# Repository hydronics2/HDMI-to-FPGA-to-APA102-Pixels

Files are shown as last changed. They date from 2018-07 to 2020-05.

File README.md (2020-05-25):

# Oregon Museum of Science & Industry (OMSI) - giant LED wall

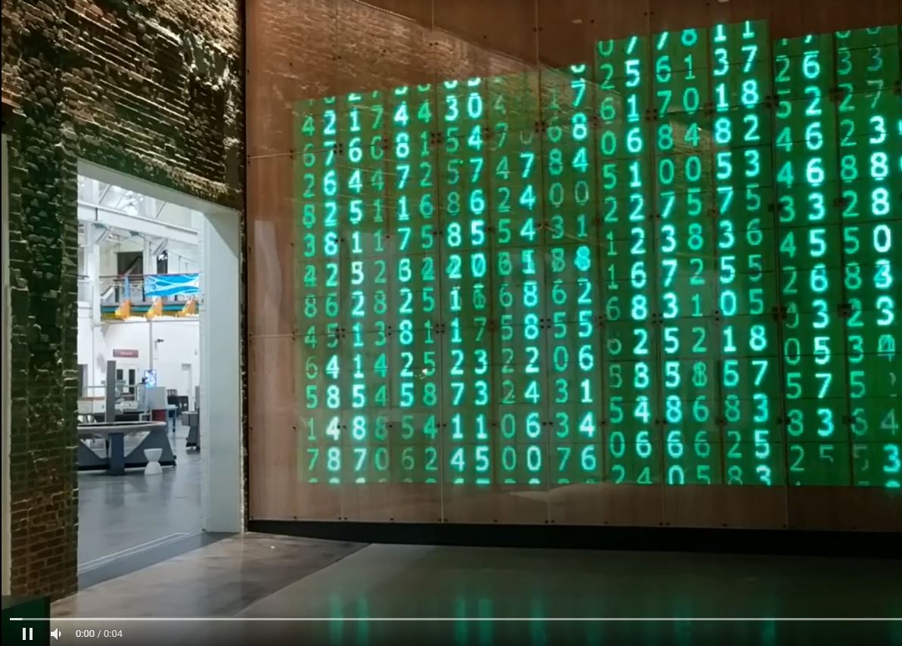
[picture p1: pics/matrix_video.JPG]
Foo (https://photos.app.goo.gl/FNSjgucNsmASgbaz8)

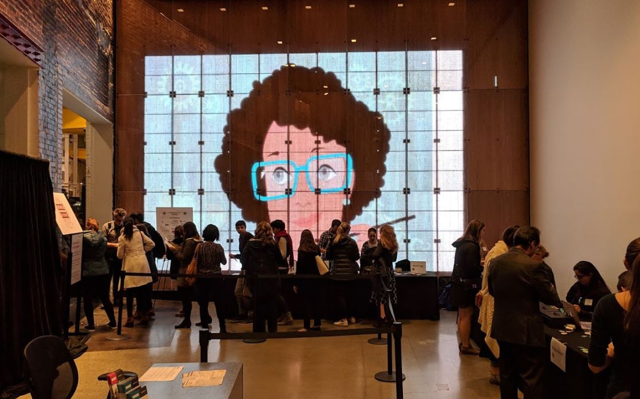
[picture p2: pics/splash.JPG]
splash

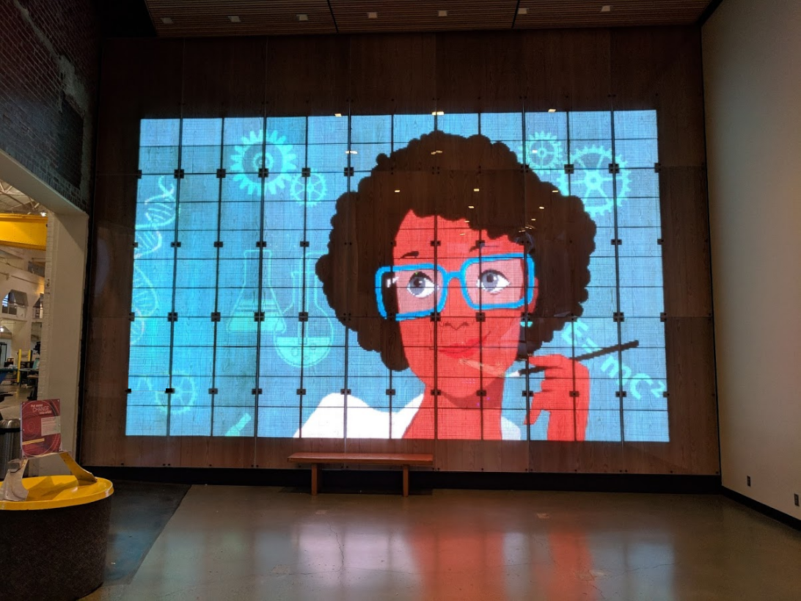
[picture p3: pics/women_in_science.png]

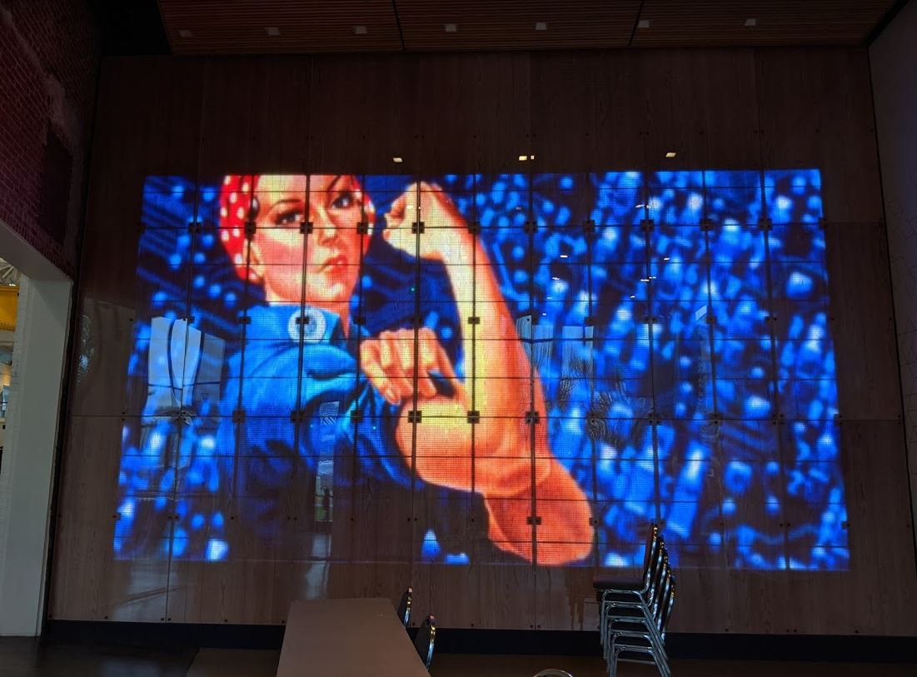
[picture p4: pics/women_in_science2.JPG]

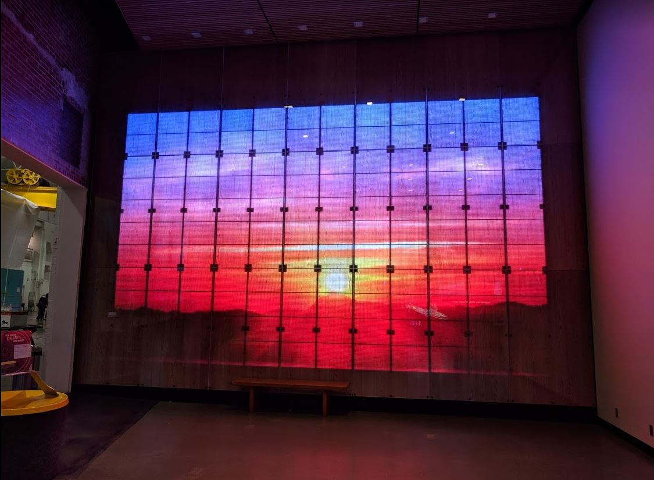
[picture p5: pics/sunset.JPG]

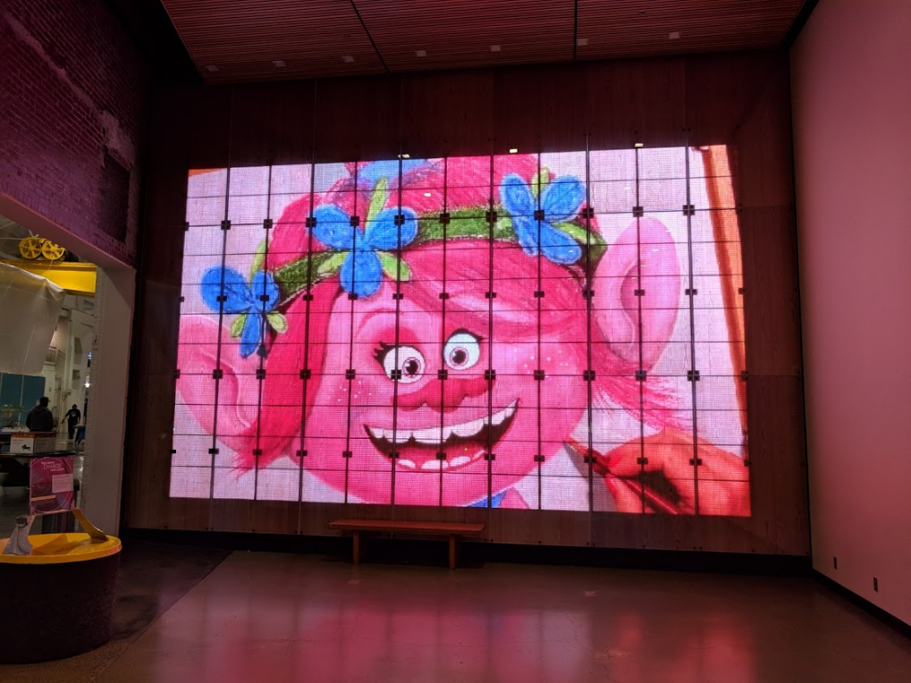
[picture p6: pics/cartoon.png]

132 APA102 LED panels, 680 pixels per panel, 90,000 pixels, 300sqft, 4 Spartan 6 Mojo FPGAs
[hackaday.io](https://hackaday.io/project/163657-hdmi-to-fpga-to-apa102)

LED Wall at Oregon Museum of Science & Industry(OMSI): https://photos.app.goo.gl/8hZoa7y9F9Lsg7Md9 (animation credit to [yassi @ openprocessing.org](https://www.openprocessing.org/user/65007))

The creative director wanted to put the LED display behind a wood grain pattern similar to the wall at Microsoft HQ. When the LEDs are off the visitor sees a seemless, unobtrusive wall. To make the LEDs pop behind the wood grain graphic we used a very brigtht APA102.

The resolution is about 24' wide by 14' high. That's 408 pixels wide 220 pixels tall. Not quite VGA.

The FPGA's boards are Spartan 6 on a Mojo development platform: https://alchitry.com/ The wall is broken down into 4 sections for 4 Mojo's and each Mojo receives the same HDMI signal but only grabs pixels for the section of LEDs it controls.

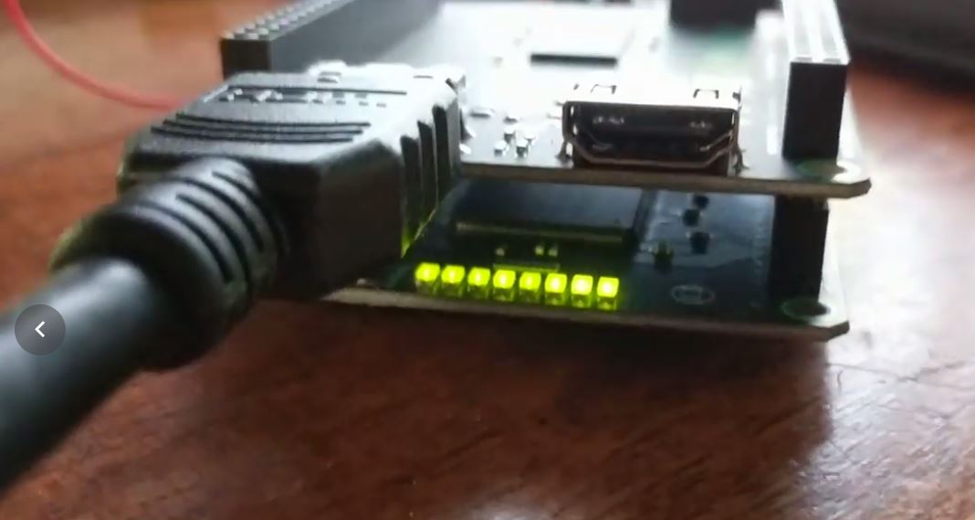
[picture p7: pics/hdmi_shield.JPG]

Alchitry has an HDMI shield for the Mojo and the FPGA code is written in their programming environment in Lucid a form of Verilog. It's great for beginners. This was my first FPGA project.

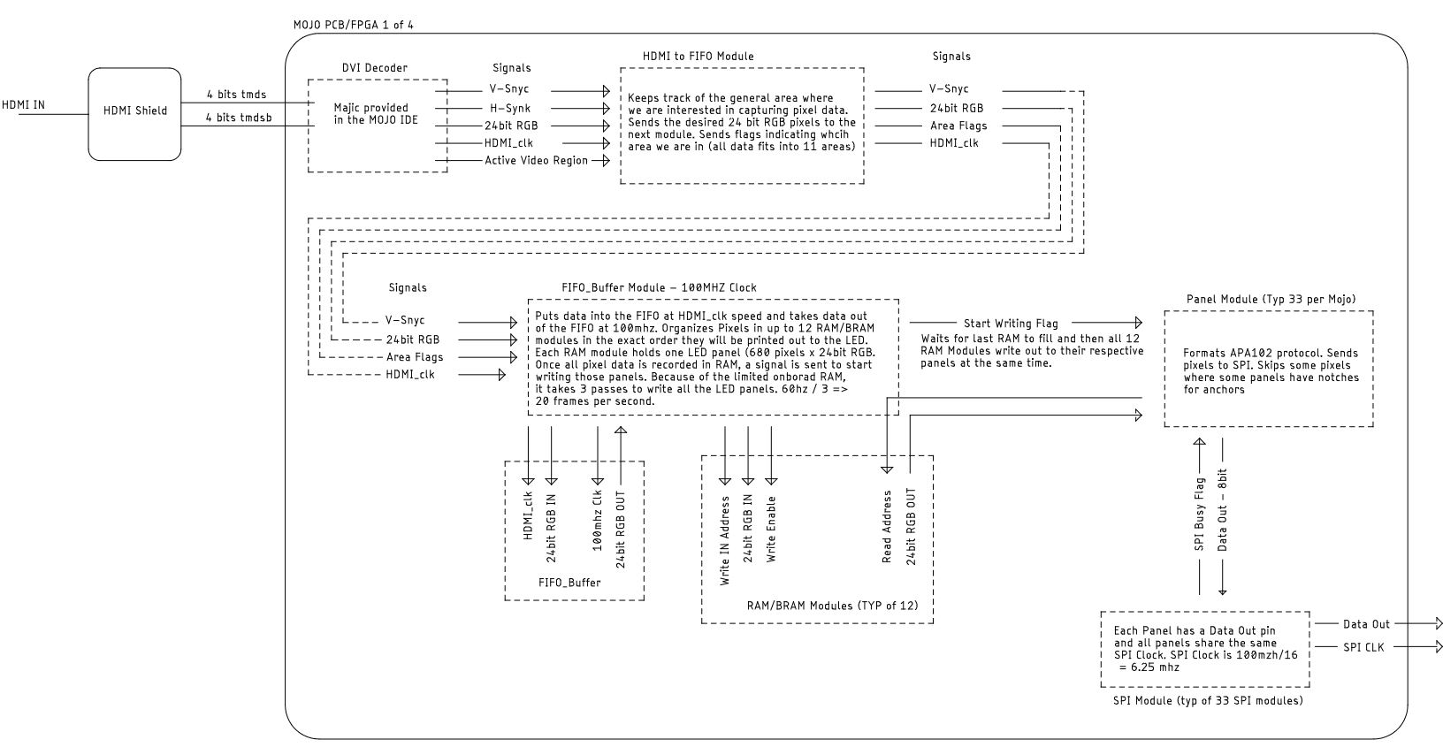
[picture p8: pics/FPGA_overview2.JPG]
overview


The HDMI signal is decoded and pixels arranged for each panel in local memory (RAM). There is just enough memory to save about 30% of the pixels so it takes 3 passes to arrange and output all the pixels... 60HZ / 3 gives us 20 frames per second. Thanks to [David Hulton](https://www.meetup.com/PNW-FPGA-Hackers-Meetup/) and Devin Boyer for sharing their mad FPGA memory tricks at [Toorcamp 2018](https://toorcamp.toorcon.net/).

The SPI clock speed for writing to the APA102 also has speed limits as we 'race the beam.' Here's a great article by [Paul Stoffregen (teensy)](https://www.pjrc.com/why-apa102-leds-have-trouble-at-24-mhz/) on these limits. The gist is the clock signals start to deteriorate between the pixels. For the 680 LEDs in our panel, I was able to write confidently at 6.25 MHZ. You can see how this clock signal is generated in any one of the 32 SPI modules in the source file under Mojo.

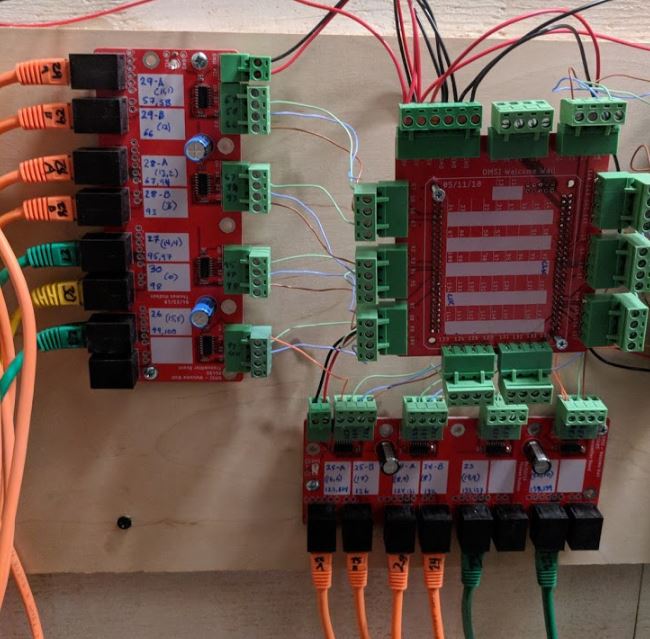
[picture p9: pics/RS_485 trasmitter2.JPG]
rs485_transmitter

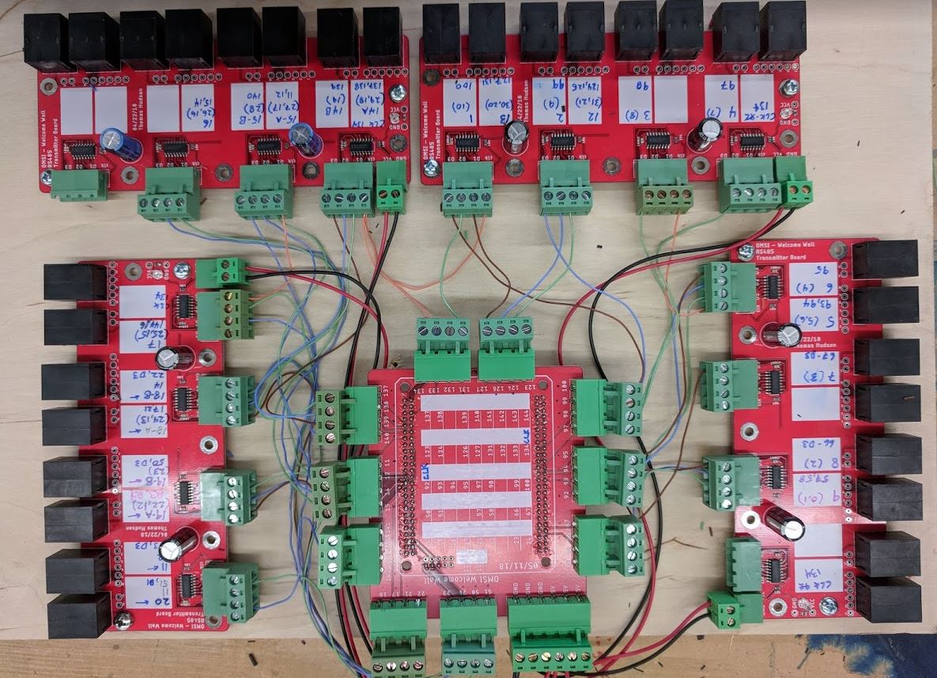
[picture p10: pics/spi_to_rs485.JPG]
foo


The FPGA generates an SPI clock and data signal to each LED panel. The signals are immediately fed from a simple shield to another custom PCB with [RS485 transmitters](https://www.digikey.com/product-detail/en/texas-instruments/AM26LV31EIDR/296-24690-1-ND/2092512) shown above. The transmitter chips output differential signal pairs that pass easily in ethernet cords over 20-30 feet to each panel location. At the LED panel, the signals are received with [transceiver](https://www.digikey.com/product-detail/en/maxlinear-inc/SP485EN-L-TR/1016-1829-1-ND/3586546) chips bacck into clock and data lines and connected to their respective LED panel. This custom PCB also has a small DC-DC voltage transformers that take a 45VDC buss down to the 5V required for the LEDs.  The below PCB has tranceiver chips and three DC-DC transformers serving 3 LED panels. Thanks to Tom Moxon with [Pattern Agents](http://patternagents.com/) for help designing this circuit.

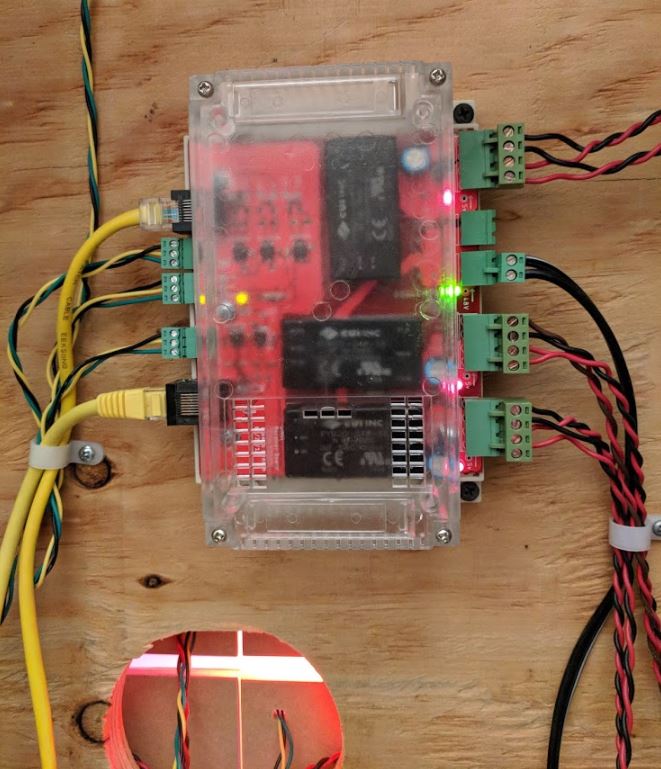
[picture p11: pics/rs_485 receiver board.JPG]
tranceivers


The led panels themselves are little more than strip LEDs that have been connected together.  We had them customized for our particular geometry by the [supplier](https://www.aliexpress.com/store/product/30-40-pixels-RGB-full-color-WS2812B-Flexible-LED-Pixel-Panel-Light-DC5V/701799_32601735218.html).

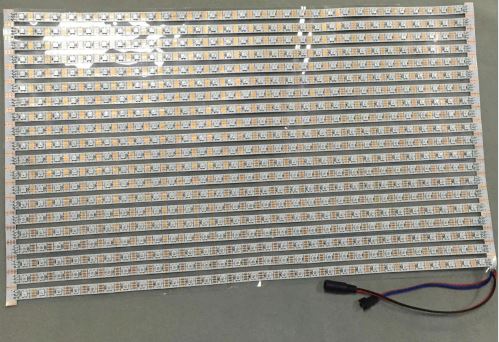
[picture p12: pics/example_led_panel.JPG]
sample


Mojo HDMI Shield: https://embeddedmicro.com/products/hdmi-shield

This design builds off of a lucid module example for decoding HDMI signals: https://embeddedmicro.com/blogs/tutorials/hdmi-shield-basics

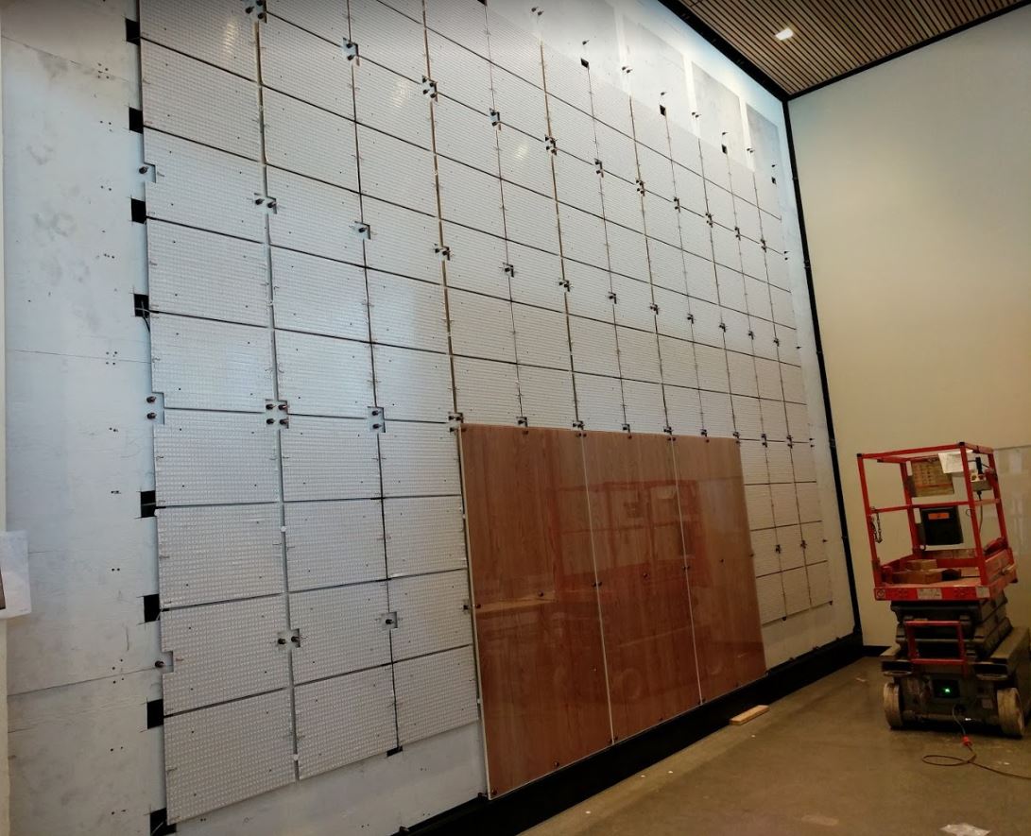
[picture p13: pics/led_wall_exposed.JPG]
exposed


Thanks to Walsh Construction for making it look easy to hang giant pieces of Acrylic exactly on target.

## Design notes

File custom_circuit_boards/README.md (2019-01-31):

# Custom Circuit Boards

We used 3 types of circuit boards.
* A simple shield for the mojo that broke out all the SPI and Clock signals to the LED panels.
* A transmitter board that sends the clock and data signal out over RS485
* A receiver board that has transceiver chips, takes the signals 

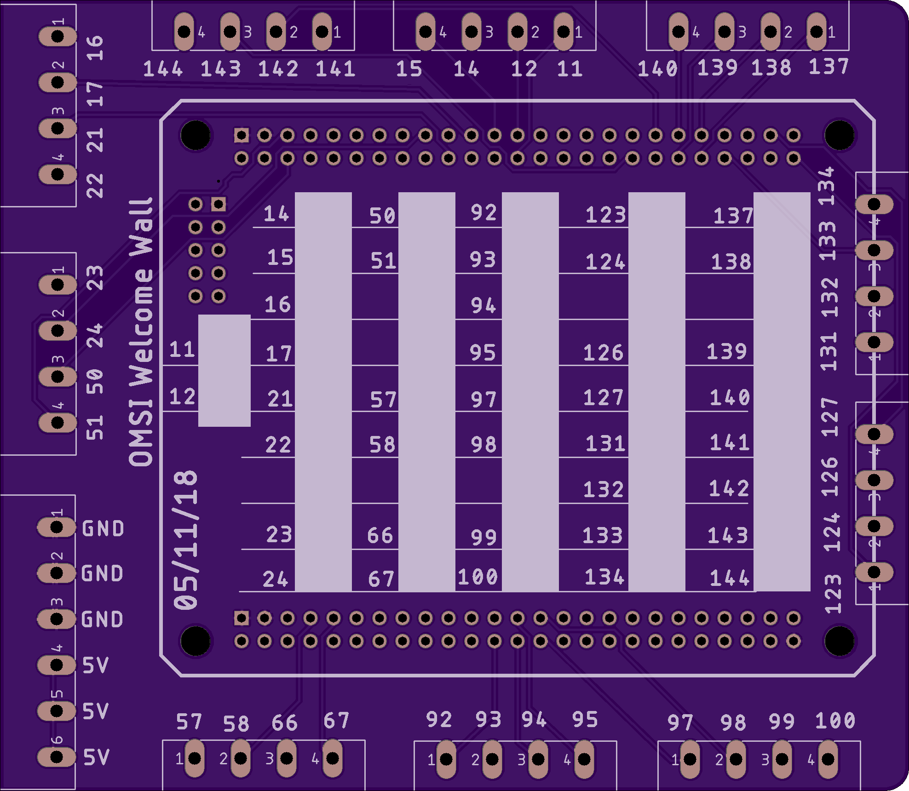
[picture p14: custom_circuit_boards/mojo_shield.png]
shield

Mojo Shield has all the pins broken out. We needed 33 SPI Data pins and the clock pin was shared across all the Panels.  The pins are broken out to 5.08mm phoenix connectors. The HDMI shield fits on the Mojo and this shield connects ontop of the HDMI shield. [Oshpark](https://oshpark.com/shared_projects/AGi8q5pp)

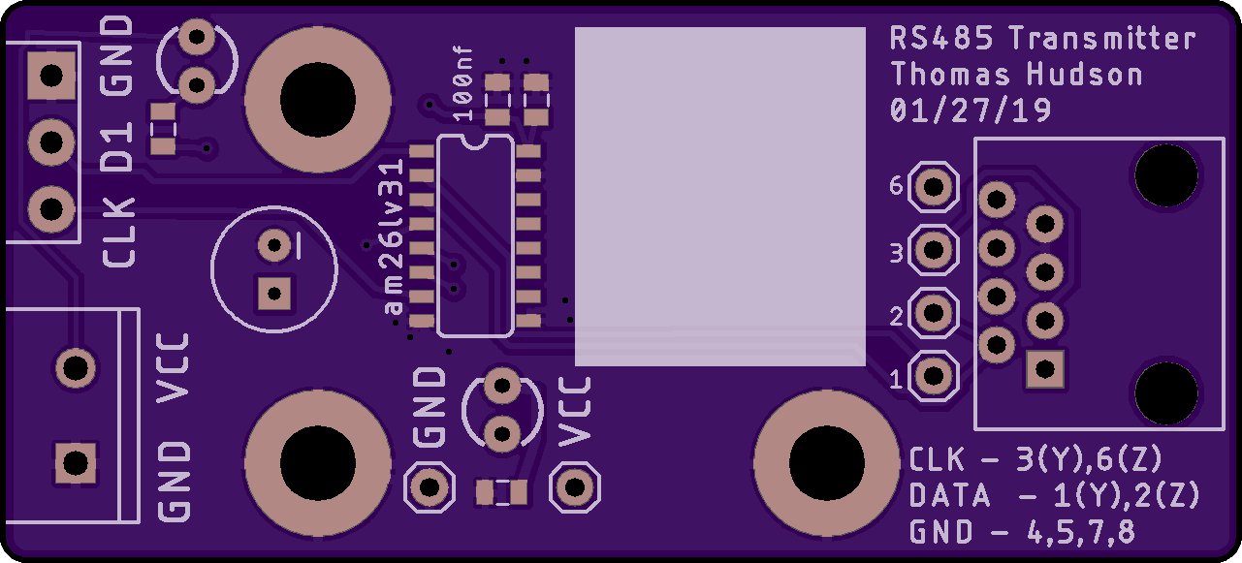
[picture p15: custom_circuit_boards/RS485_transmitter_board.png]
transmitter

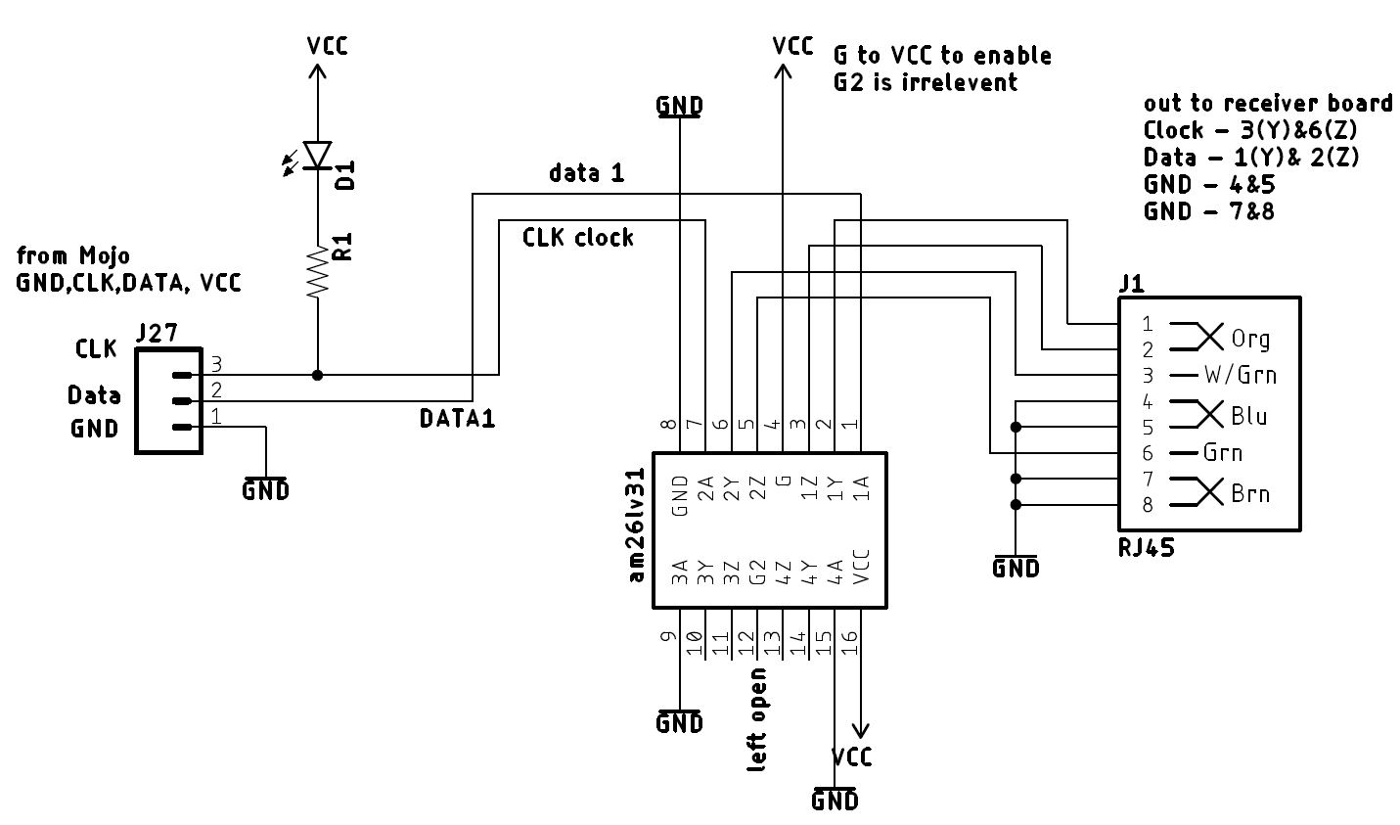
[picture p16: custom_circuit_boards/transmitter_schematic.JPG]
schematic


The transmitter board takes two SPI signals (Clock and Data) and passes the signals through an RS485 transmitter chip. The differential signals are routed to an ethernet jack. This board could have been integrated into the Mojo shield to reduce noise but my disigning, programming, prototyping, and installing timelines compressed the schedule and I had to learn as I went. [Oshpark](https://oshpark.com/shared_projects/nhExJAWv)

* transmitter chip: Texas Instrument AM27LV31 296-24690-1-ND
* RJ45 ethernet jack: 380-1316-5-ND
* 

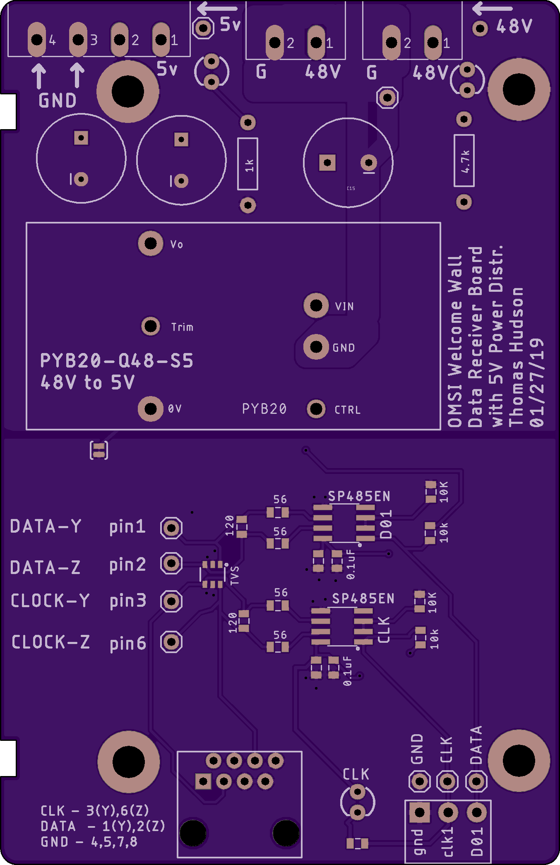
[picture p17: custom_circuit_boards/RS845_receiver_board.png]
receiver

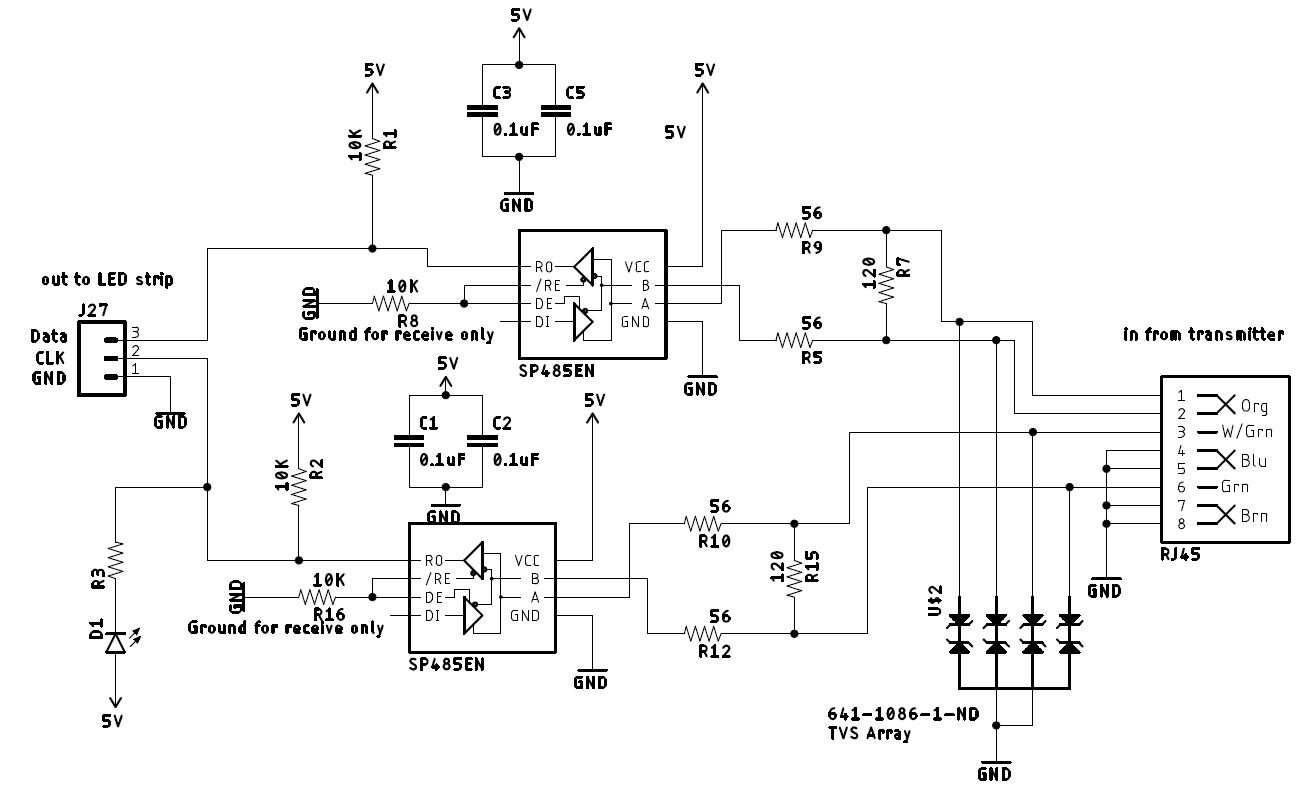
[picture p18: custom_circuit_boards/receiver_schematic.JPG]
receiver schematic


The receiver board receives RS485 signals via a RJ485 ethernet jack. Converts the two differential pairs back into clock and data SPI signals and connects to one LED panel. The board also has a DC-to-DC converter that takes 45V to 5V to supply to the LED panel. I did not put the TVS protection diodes on the boards but added them on just the last few boards I made when troubleshooting noise issues.  Also, in addition to the 120ohm termination resistors on the RS485 bus, the original boards have 4.7k pullup and pulldown resistors on the bus. Modern RS485 chips have whats called "failsafe" against idle(no Data) conditions that these resistors are meant to deter.... so I left them out of these last few single signal boards shown here. [Oshpark](https://oshpark.com/shared_projects/qSwC1Fum)

* Trnsceiver Chip: SP485EN, 1016-1829-1-ND
* RJ45 Ethernet Jack: 380-1316-5-ND
* DC-DC converter - PYB20-Q48-S5

* [Mojo Development Board](https://alchitry.com/products/mojo-v3)
* [HDMI Shield](https://alchitry.com/products/hdmi-shield)
* [RS485 transmitter chips](https://www.digikey.com/product-detail/en/texas-instruments/AM26LV31EIDR/296-24690-1-ND/2092512) shown above.
* [RS485 transceiver chips](https://www.digikey.com/product-detail/en/maxlinear-inc/SP485EN-L-TR/1016-1829-1-ND/3586546) chips
* [Mojo HDMI Shield](https://embeddedmicro.com/products/hdmi-shield)

splash
rs485_transmitter
tranceivers

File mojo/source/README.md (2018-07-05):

# mojo_fpga

This design takes an HDMI signal and outputs a 34 long x 20 high grid of APA102 leds.

The hardware consists of a Spartan 6 FPGA on an Mojo development board by Embedded Micro... using their IDE written in Lucid which is similar to Verilog: https://embeddedmicro.com/products/mojo-v3

Also uses the HDMI shield for the Mojo by Embedded Micro: https://embeddedmicro.com/products/hdmi-shield

This design builds off of a lucid module example for decoding HDMI signal: https://embeddedmicro.com/blogs/tutorials/hdmi-shield-basics

There is something wrong with the vsync signal so I imported the dvi_decoder directly into the top module and teased out a start frame indicator.

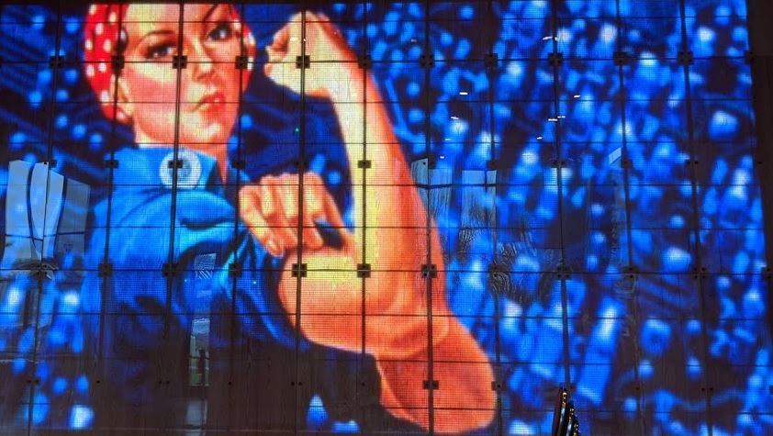
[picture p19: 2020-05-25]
pics/women_in_science3.JPG

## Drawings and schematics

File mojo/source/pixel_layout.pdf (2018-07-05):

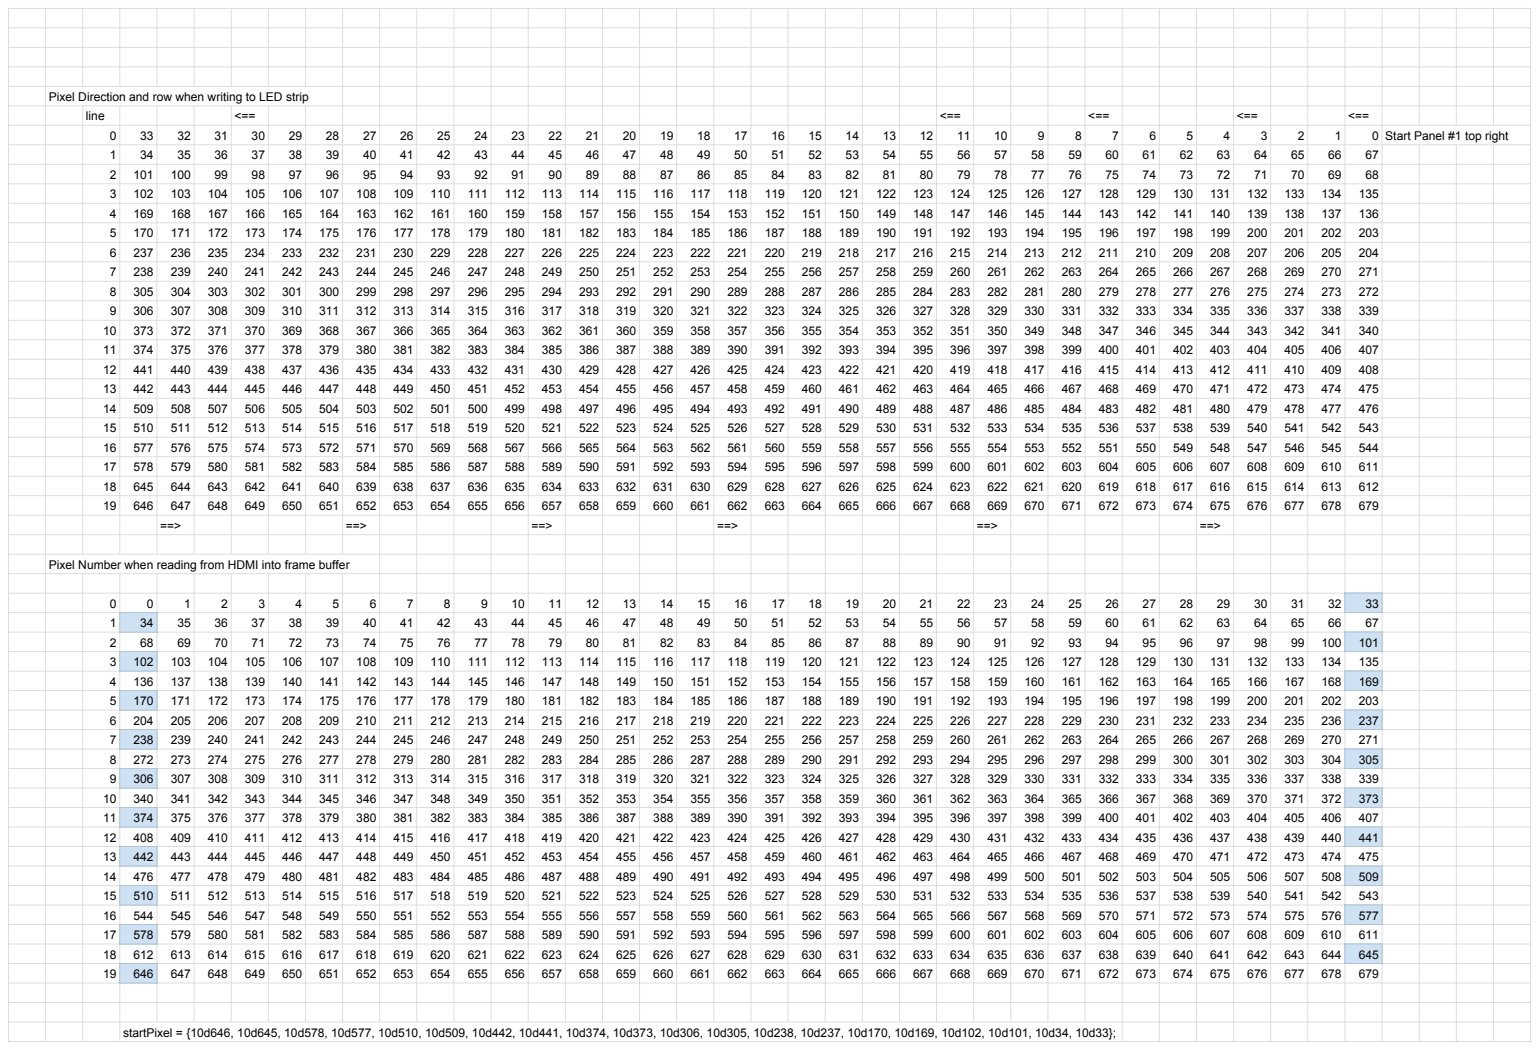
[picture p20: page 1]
line; 0 Start Panel #1 top right; startPixel = {10d646, 10d645, 10d578, 10d577, 10d510, 10d509, 10d442, 10d441, 10d374, 10d373, 10d306, 10d305, 10d238, 10d237, 10d170, 10d169, 10d102, 10d101, 10d34, 10d33};

Pixel Direction and row when writing to LED strip

Pixel Number when reading from HDMI into frame buffer

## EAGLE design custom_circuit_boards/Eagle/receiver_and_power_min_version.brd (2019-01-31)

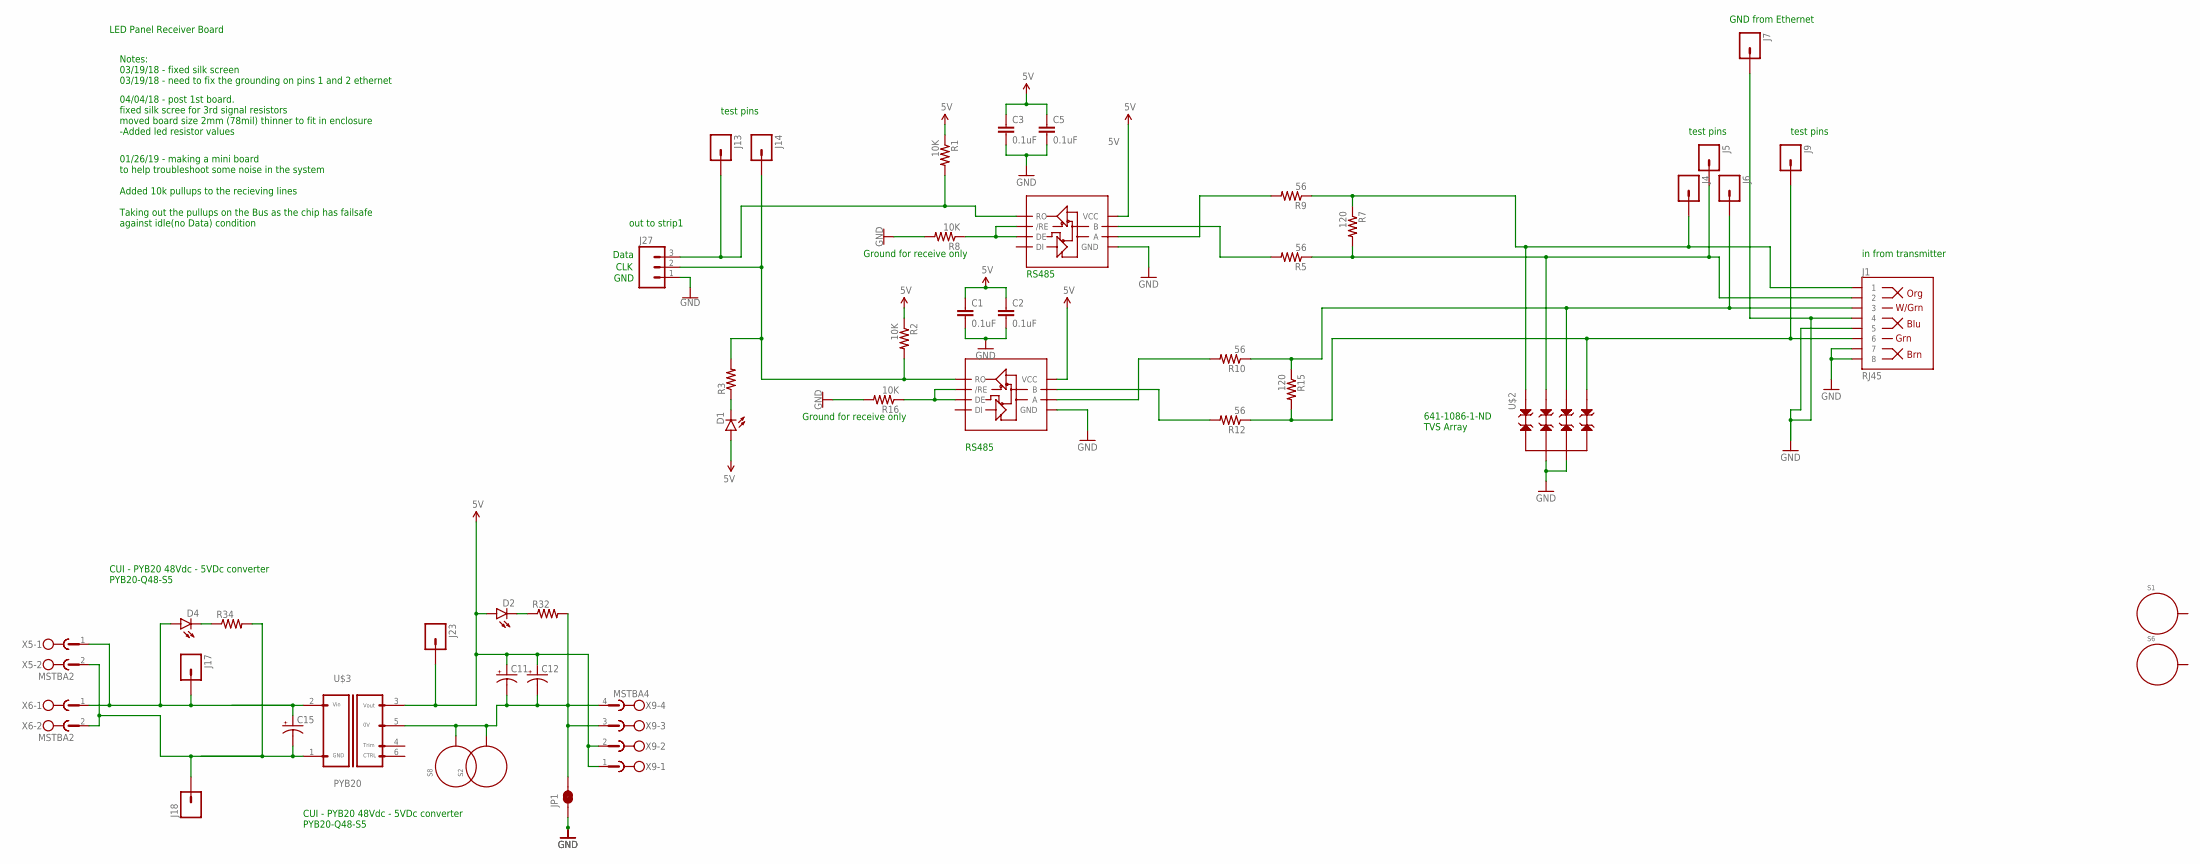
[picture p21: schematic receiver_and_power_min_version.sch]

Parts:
C1, C2, C3, C5: 0.1uF; 0805
C11, C12, C15: CAP_POLPTH4; CPOL-RADIAL-1000UF-25V
D1, D2, D4: LED3MM
J1: RJ45; RJ45-8
J4, J5, J6, J7, J9, J13, J14, J17, J18, J23: M01PTH; 1X01
J27: M03SCREW; SCREWTERMINAL-3.5MM-3
JP1: JUMPER-PAD-2-NC_BY_TRACE; PAD-JUMPER-2-NC_BY_TRACE_YES_SILK
R1, R2, R8, R16: 10K; 0805
R3: RESISTOR0805-RES; 0805
R5, R9, R10, R12: 56; 0805
R7, R15: 120; 0805
R32, R34: RESISTORPTH-1/4W; AXIAL-0.4
S1, S2, S6, S8: STANDOFF_ELECTRICAL5-32; STANDOFF_ELECTRICAL_5_32
U1, U2: ST1480ACSOIC; SO08
U$2: TVS_ARRAY; SOT26
U$3: PYB20; CUI_PYB20_PCB_DC_DC
X5, X6: MSTBA2
X9: MSTBA4

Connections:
5GND1: C11.2 (-), C12.2 (-), JP1.2, R32.P$2 (2), S2.P1, S8.P1, U$3.5 (0V), X9.3, X9.4
5V: C1.1, C2.1, C3.1, C5.1, C11.1 (+), C12.1 (+), D1.A, D2.A, J23.1, R1.1, R2.1, U1.8 (VCC), U2.8 (VCC), U$3.3 (V+), X9.1, X9.2
48GND: C15.-, J18.1, R34.P$2 (2), U$3.1 (GND1), X5.2, X6.2
48V: C15.+, D4.A, J17.1, U$3.2 (VIN), X5.1, X6.1
A: R9.2, U1.6 (A)
A1: R10.2, U2.6 (A)
AO: J1.1, J4.1, R7.1, R9.1, U$2.1
AO1: J1.3, J6.1, R10.1, R15.1, U$2.4
B: R5.2, U1.7 (B)
B1: R12.2, U2.7 (B)
BO: J1.2, J5.1, R5.1, R7.2, U$2.3
BO1: J1.6, J9.1, R12.1, R15.2, U$2.6
DE: R8.1, U1.2 (/RE), U1.3 (DE)
DE1: R16.1, U2.2 (/RE), U2.3 (DE)
GND: C1.2, C2.2, C3.2, C5.2, J1.4, J1.5, J1.7, J1.8, J7.1, J27.1, JP1.1, R8.2, R16.2, U1.5 (GND), U2.5 (GND), U$2.2, U$2.5
unnamed: D1.K (C), R3.1
unnamed: D4.K (C), R34.P$1 (1)
unnamed: D2.K (C), R32.P$1 (1)
RXD: J13.1, J27.3, R1.2, U1.1 (RO)
RXD1: J14.1, J27.2, R2.2, R3.2, U2.1 (RO)

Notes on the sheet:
in from transmitter
test pins
Ground for receive only
out to strip1
LED Panel Receiver Board
GND from Ethernet
RS485
Notes: 03/19/18 - fixed silk screen 03/19/18 - need to fix the grounding on pins 1 and 2 ethernet
GND
CLK
Data
CUI - PYB20 48Vdc - 5VDc converter PYB20-Q48-S5
04/04/18 - post 1st board. fixed silk scree for 3rd signal resistors moved board size 2mm (78mil) thinner to fit in enclosure -Added led resistor values
01/26/19 - making a mini board to help troubleshoot some noise in the system Added 10k pullups to the recieving lines Taking out the pullups on the Bus as the chip has failsafe against idle(no Data) condition
641-1086-1-ND TVS Array

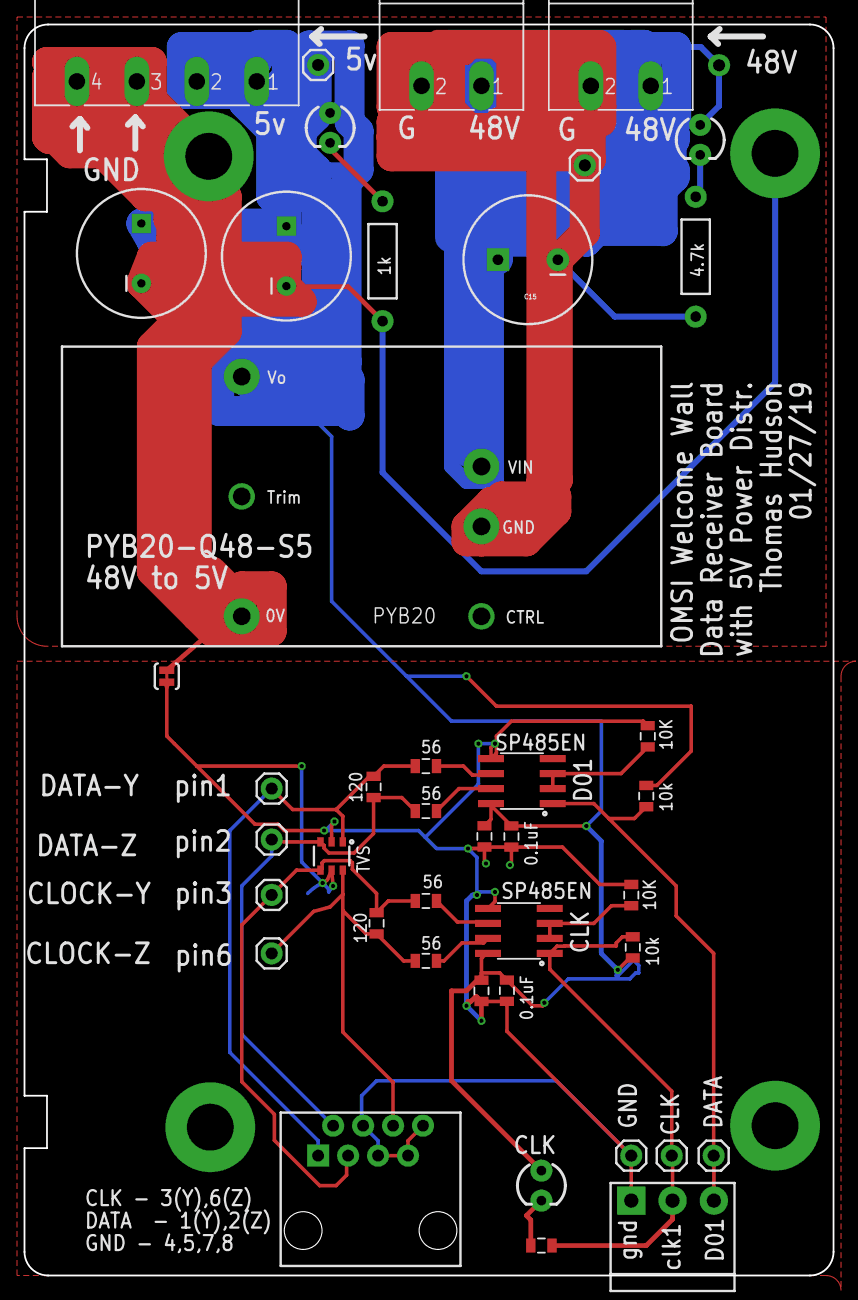
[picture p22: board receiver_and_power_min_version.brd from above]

Board: 2 copper layers, 68.6 x 106.0 mm, 47 parts (1 on the bottom side), 20 nets.

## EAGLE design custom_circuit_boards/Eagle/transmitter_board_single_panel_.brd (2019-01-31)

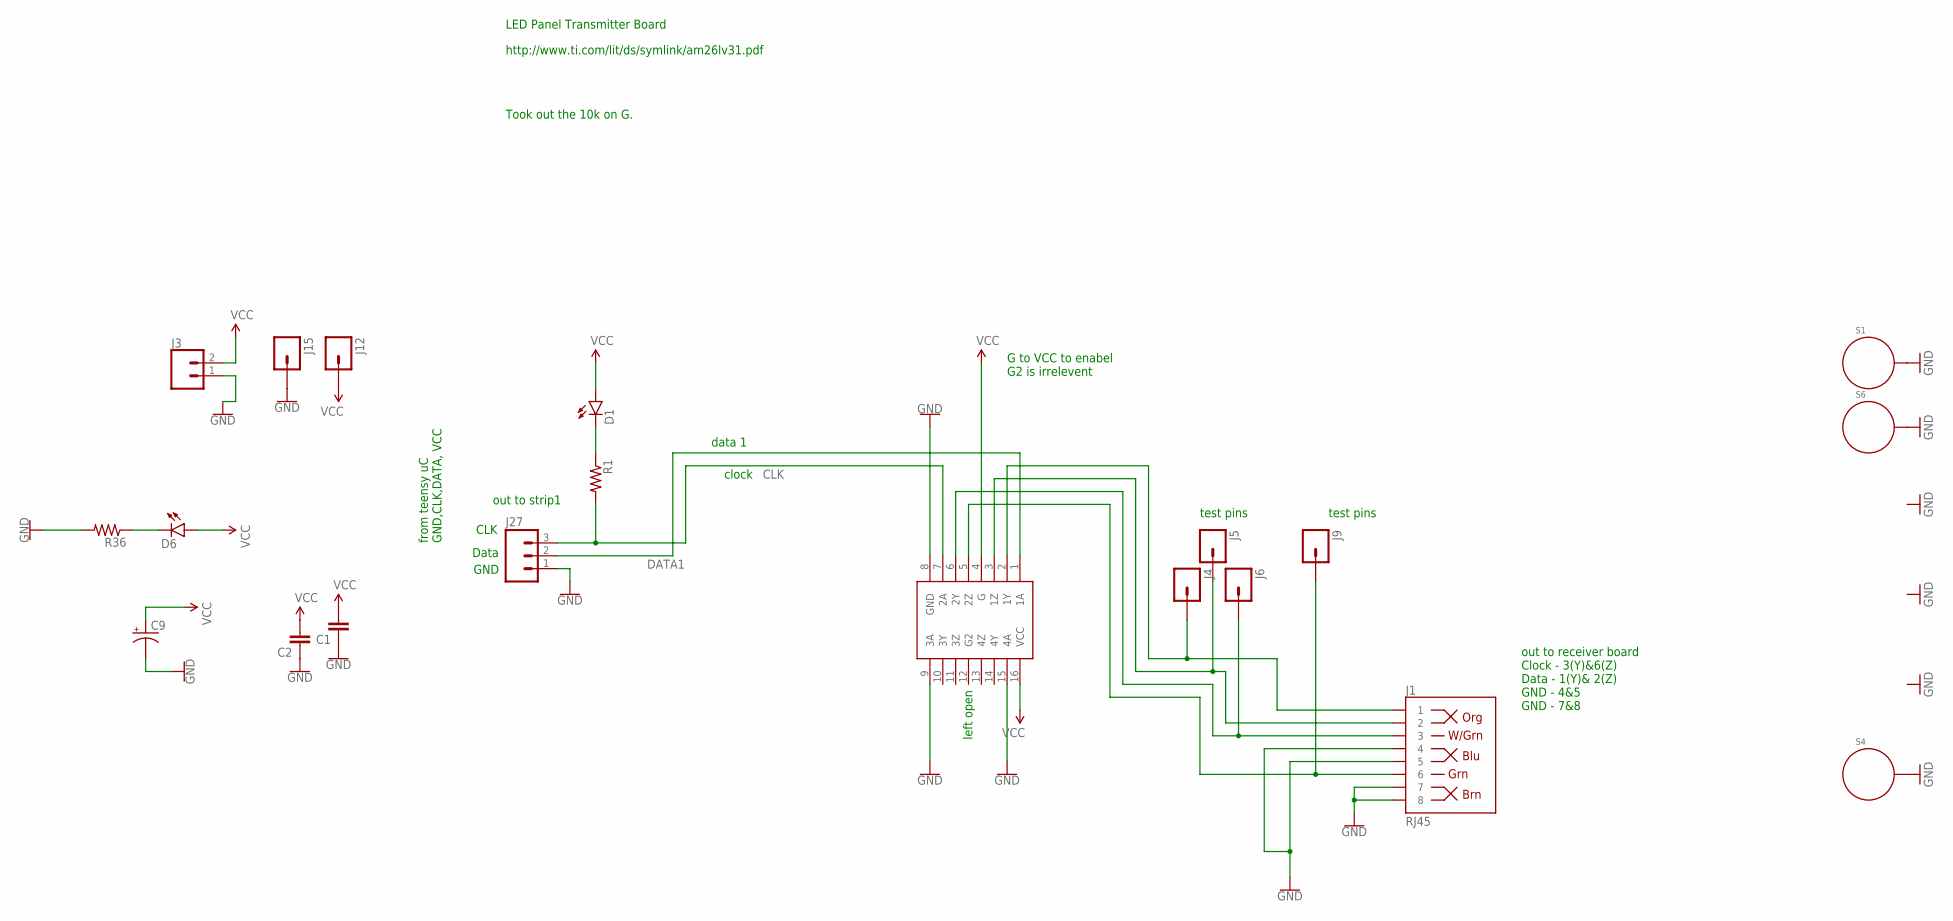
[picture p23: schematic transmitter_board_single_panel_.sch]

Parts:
C1, C2: CAP0805; 0805
C9: CAP_POLPTH1; CPOL-RADIAL-100UF-25V
D1, D6: LED3MM
J1: RJ45; RJ45-8
J3: CONN_025MM; SCREWTERMINAL-5MM-2
J4, J5, J6, J9, J12, J15: M01PTH; 1X01
J27: M03SCREW; SCREWTERMINAL-3.5MM-3
R1, R36: RESISTOR0805-RES; 0805
S1, S4, S6: STANDOFF_ELECTRICAL5-32; STANDOFF_ELECTRICAL_5_32
U$1: AM26LV31_QUAD_LINE_DRIVER; SO016

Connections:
CLK: J27.3, R1.2, U$1.7 (2A)
DATA1: J27.2, U$1.1 (1A)
GND: C1.1, C2.1, C9.2 (-), J1.4, J1.5, J1.7, J1.8, J3.1, J15.1, J27.1, R36.2, S1.P1, S4.P1, S6.P1, U$1.8 (GND), U$1.9 (3A), U$1.15 (4A)
unnamed: J1.1, J4.1, U$1.2 (1Y)
unnamed: J1.2, J5.1, U$1.3 (1Z)
unnamed: J1.3, J6.1, U$1.6 (2Y)
unnamed: J1.6, J9.1, U$1.5 (2Z)
unnamed: D1.K (C), R1.1
unnamed: D6.K (C), R36.1
VCC: C1.2, C2.2, C9.1 (+), D1.A, D6.A, J3.2, J12.1, U$1.4 (G), U$1.16 (VCC)

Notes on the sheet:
out to receiver board Clock - 3(Y)&6(Z) Data - 1(Y)& 2(Z) GND - 4&5 GND - 7&8
test pins
from teensy uC GND,CLK,DATA, VCC
LED Panel Transmitter Board
data 1
clock
http://www.ti.com/lit/ds/symlink/am26lv31.pdf
G to VCC to enabel G2 is irrelevent
left open
Took out the 10k on G.
out to strip1
GND
CLK
Data

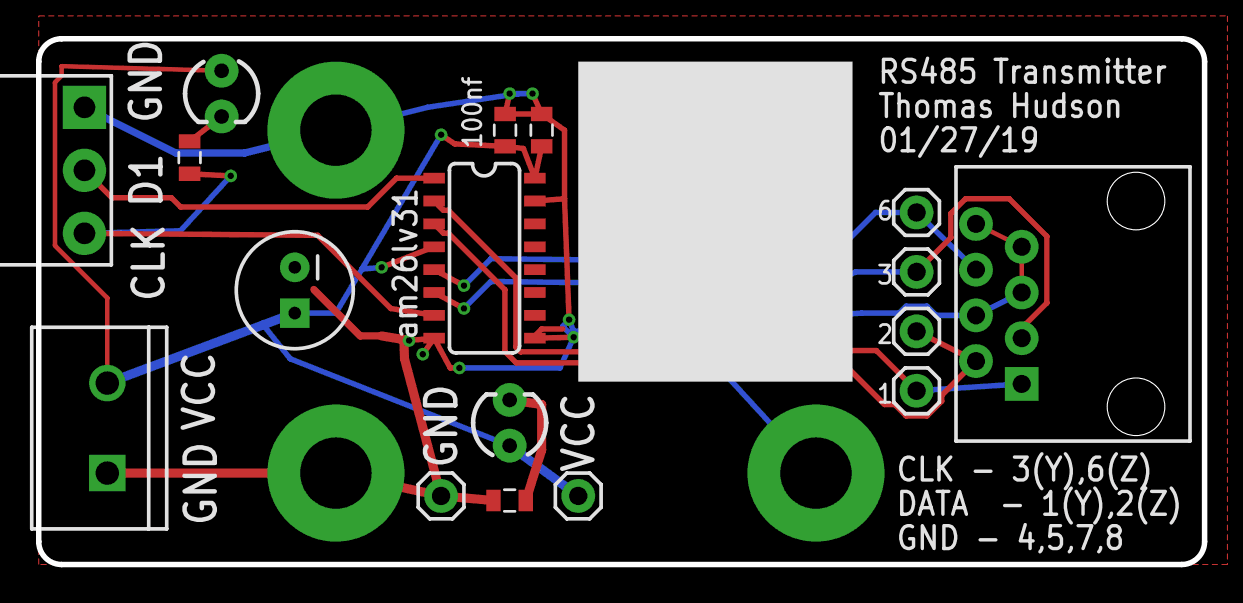
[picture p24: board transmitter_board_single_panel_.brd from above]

Board: 2 copper layers, 64.8 x 29.2 mm, 20 parts (0 on the bottom side), 10 nets.

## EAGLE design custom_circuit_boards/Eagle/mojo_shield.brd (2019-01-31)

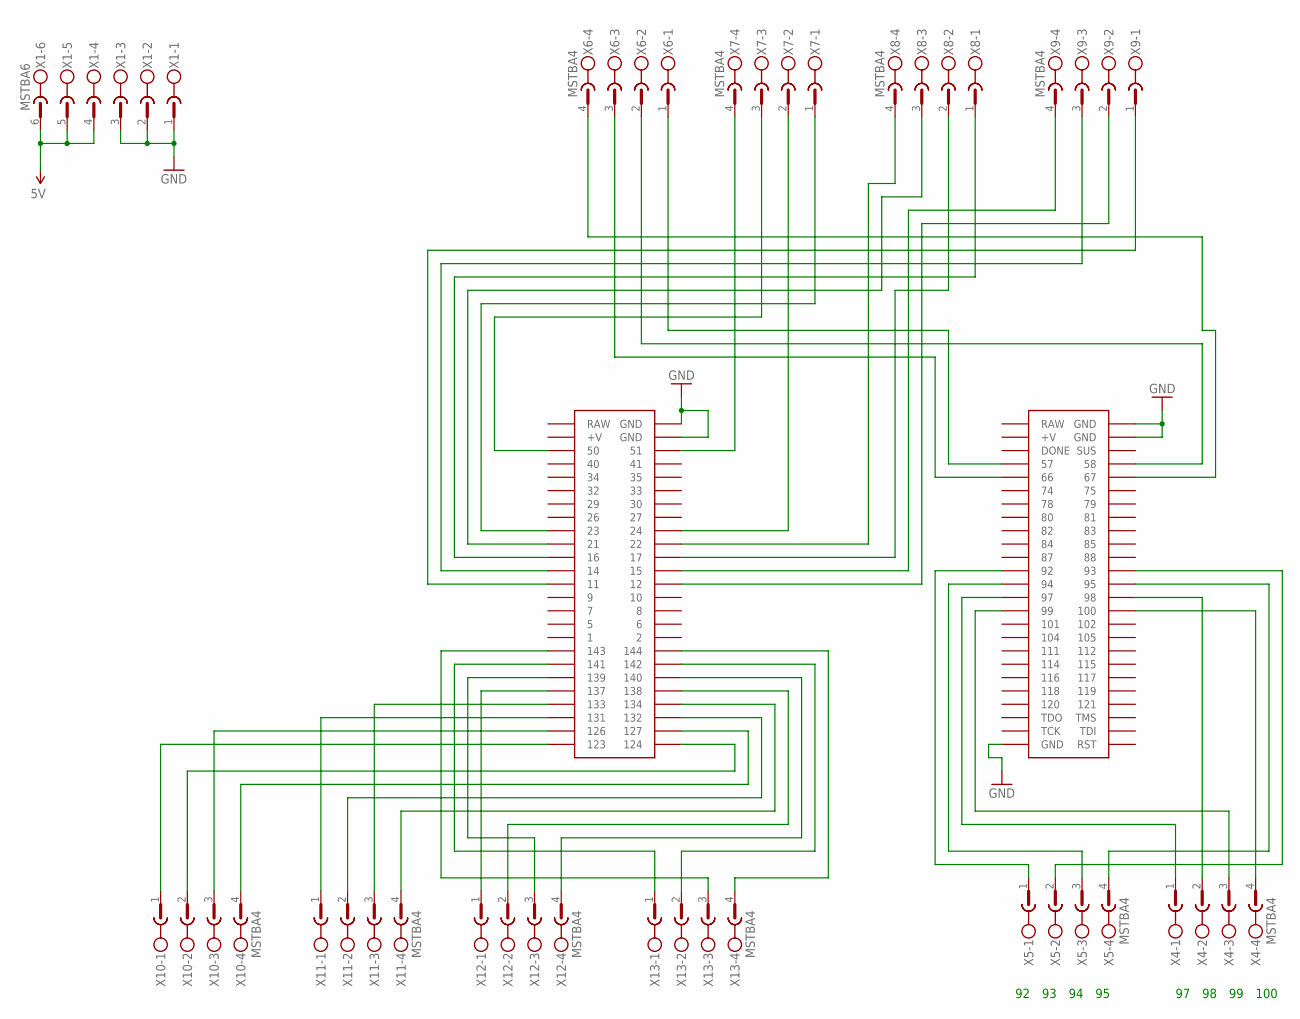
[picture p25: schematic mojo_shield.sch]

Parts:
U$1: MOJO_V2V3_NO_LABEL; MOJO_V3_NO_LABEL
X1: MSTBA6
X4, X5, X6, X7, X8, X9, X10, X11, X12, X13: MSTBA4

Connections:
5V: X1.4, X1.5, X1.6
+V: U$1.V@1 (+V), U$1.V@2 (+V)
AREF: U$1.AREF
GND: U$1.GND@1 (GND), U$1.GND@2 (GND), U$1.GND@3 (GND), U$1.GND@4 (GND), U$1.GND@5 (GND), U$1.GND@6 (GND), X1.1, X1.2, X1.3
unnamed: U$1.50, X7.3
unnamed: U$1.51, X7.4
unnamed: U$1.23, X7.1
unnamed: U$1.24, X7.2
unnamed: U$1.11, X9.1
unnamed: U$1.12, X9.2
unnamed: U$1.15, X9.4
unnamed: U$1.17, X8.2
unnamed: U$1.22, X8.4
unnamed: U$1.21, X8.3
unnamed: U$1.16, X8.1
unnamed: U$1.14, X9.3
unnamed: U$1.133, X11.3
unnamed: U$1.134, X11.4
unnamed: U$1.123, X10.1
unnamed: U$1.124, X10.2
unnamed: U$1.99, X4.3
unnamed: U$1.100, X4.4
unnamed: U$1.92, X5.1
unnamed: U$1.93, X5.2
unnamed: U$1.66, X6.3
unnamed: U$1.57, X6.1
unnamed: U$1.58, X6.2
unnamed: U$1.67, X6.4
unnamed: U$1.94, X5.3
unnamed: U$1.97, X4.1
unnamed: U$1.95, X5.4
unnamed: U$1.98, X4.2
unnamed: U$1.132, X11.2
unnamed: U$1.127, X10.4
unnamed: U$1.131, X11.1
unnamed: U$1.126, X10.3
unnamed: U$1.137, X12.1
unnamed: U$1.138, X12.2
unnamed: U$1.144, X13.4
unnamed: U$1.142, X13.2
unnamed: U$1.140, X12.4
unnamed: U$1.143, X13.3
unnamed: U$1.141, X13.1
unnamed: U$1.139, X12.3
RAW: U$1.RAW@1 (RAW), U$1.RAW@2 (RAW)

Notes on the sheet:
100

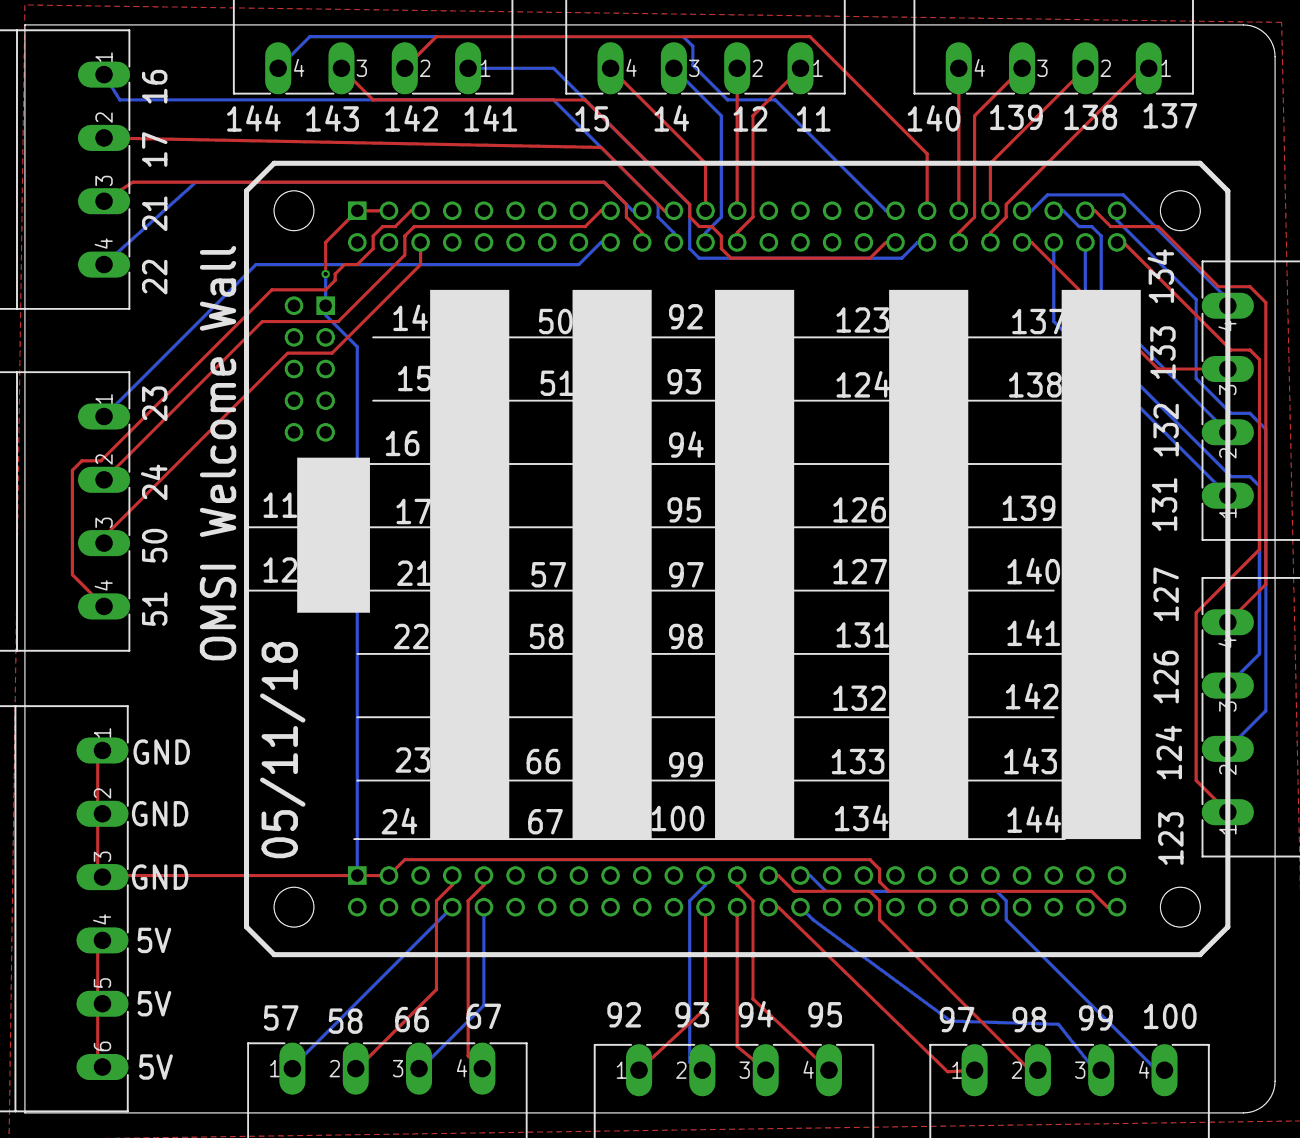
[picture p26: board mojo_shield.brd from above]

Board: 2 copper layers, 100.3 x 87.3 mm, 12 parts (0 on the bottom side), 44 nets.

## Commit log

2018-06-20 added contraint file for led strip pins
2018-07-05 top row working with new spi speed and at 150mhz clock
2018-07-06 6 panels writing.. the middle panels if each row is flickering.. at the bottom. look slike spi
2018-07-13 fixed frame 5 skipping... Signed-off-by: hydronics2 <hydronics@gmail.com>
2018-07-18 added 4 total frame buffers => 12 simple ram modules for 12 panels

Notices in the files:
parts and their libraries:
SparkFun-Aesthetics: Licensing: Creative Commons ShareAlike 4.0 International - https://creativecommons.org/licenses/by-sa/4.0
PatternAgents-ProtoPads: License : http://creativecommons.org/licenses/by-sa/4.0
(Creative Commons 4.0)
